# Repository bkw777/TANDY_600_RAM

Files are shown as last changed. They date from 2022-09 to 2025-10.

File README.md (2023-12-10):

# SRAM modules for TANDY 600

There are several versions to choose from. They all work the same. Just pick whichever you like based on size, cost of parts, ease of soldering, ease of installing, etc.

[Surface-Mount single-bank 96K](#standard-version) easy to solder, polarity keyed, more expensive  
[Through-Hole single-bank 96K](#through-hole-version) same as above, plus socketable/removable chips  
[Tiny single-bank 96K](#tiny-version) more difficult to solder, miniaturized mostly just as a stunt  
[Tiny dual-bank 192K](#dual-version) most practical way to get all 192K if you can manage the soldering

  
  
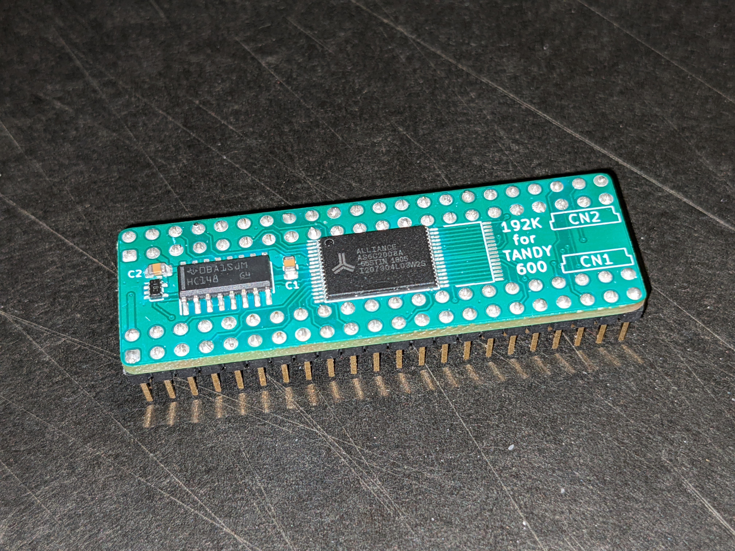
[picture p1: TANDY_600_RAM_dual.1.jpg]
  
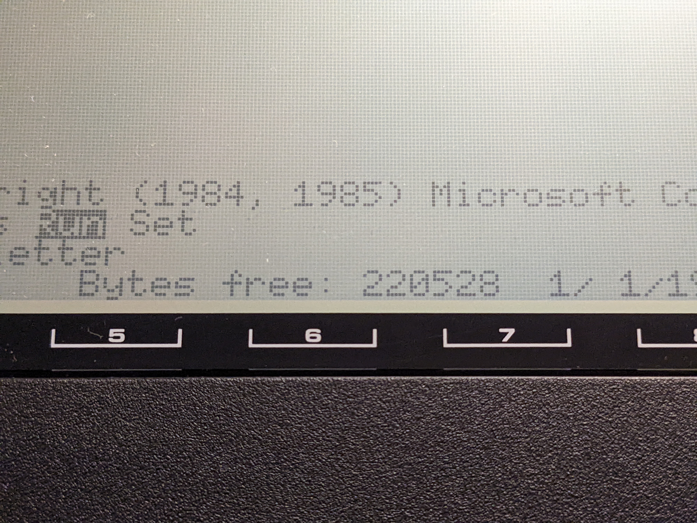
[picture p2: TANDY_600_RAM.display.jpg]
  

## Standard Version  
<!-- [PCB from OSHPark](https://oshpark.com/shared_projects/nBVWvJ2W)  -->
[PCB for STANDARD version from PCBWAY](https://www.pcbway.com/project/shareproject/TANDY_600_RAM.html)  
[BOM for STANDARD version from DigiKey](https://www.digikey.com/short/mjtb7rnn)

<!-- [Gerbers](../../releases/latest) -->

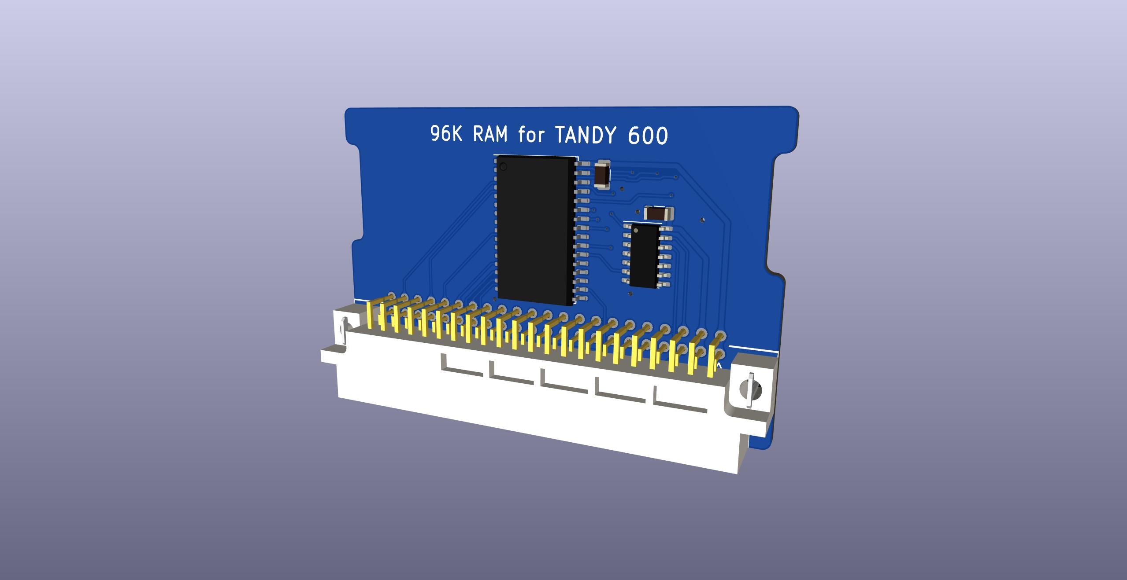
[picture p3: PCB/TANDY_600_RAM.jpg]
  
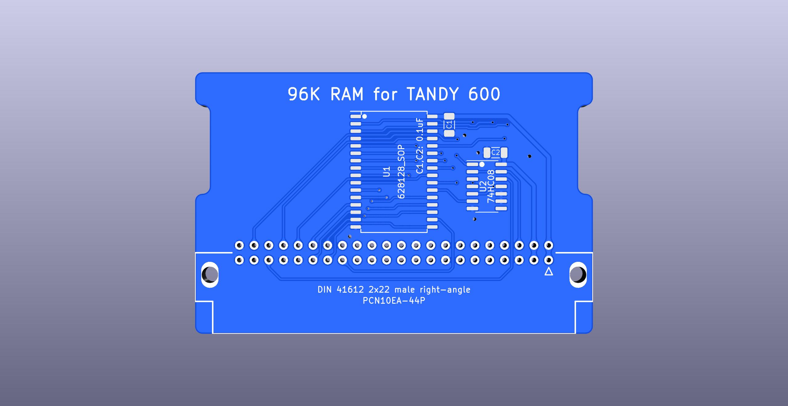
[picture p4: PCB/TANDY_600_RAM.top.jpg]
  
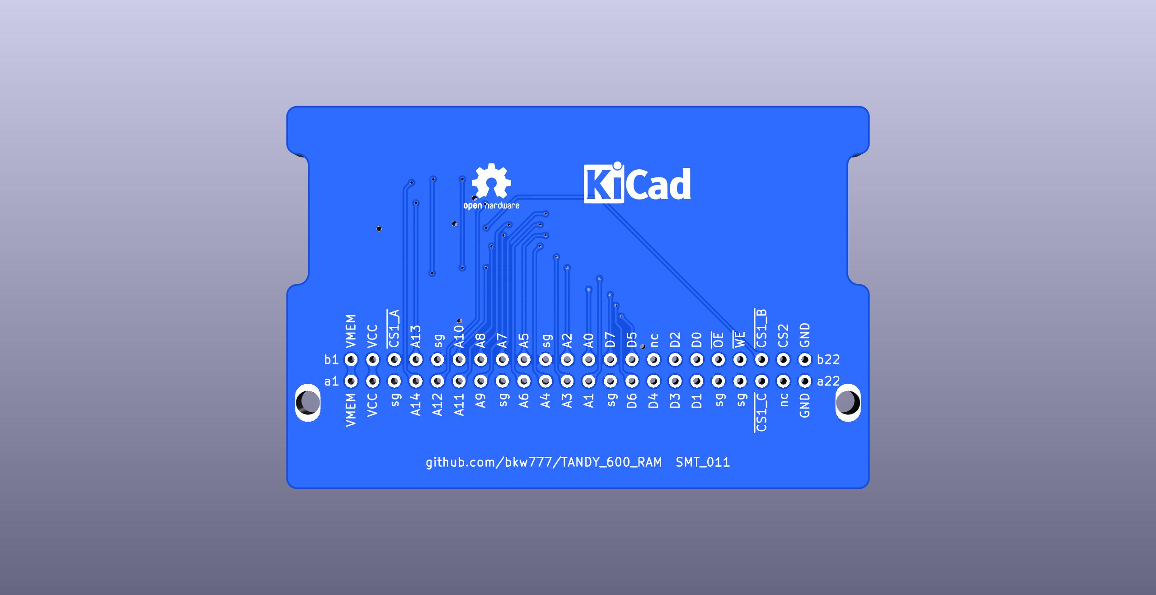
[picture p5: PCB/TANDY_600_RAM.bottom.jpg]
  
  
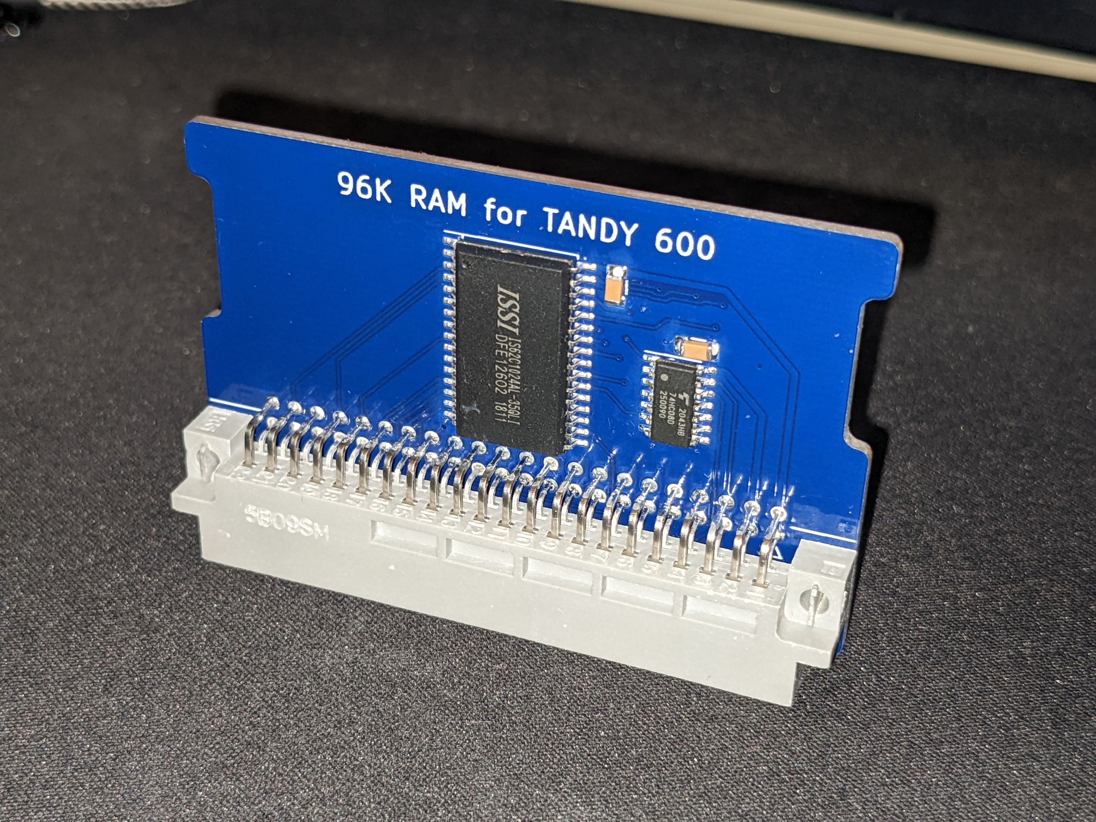
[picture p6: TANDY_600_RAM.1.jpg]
  
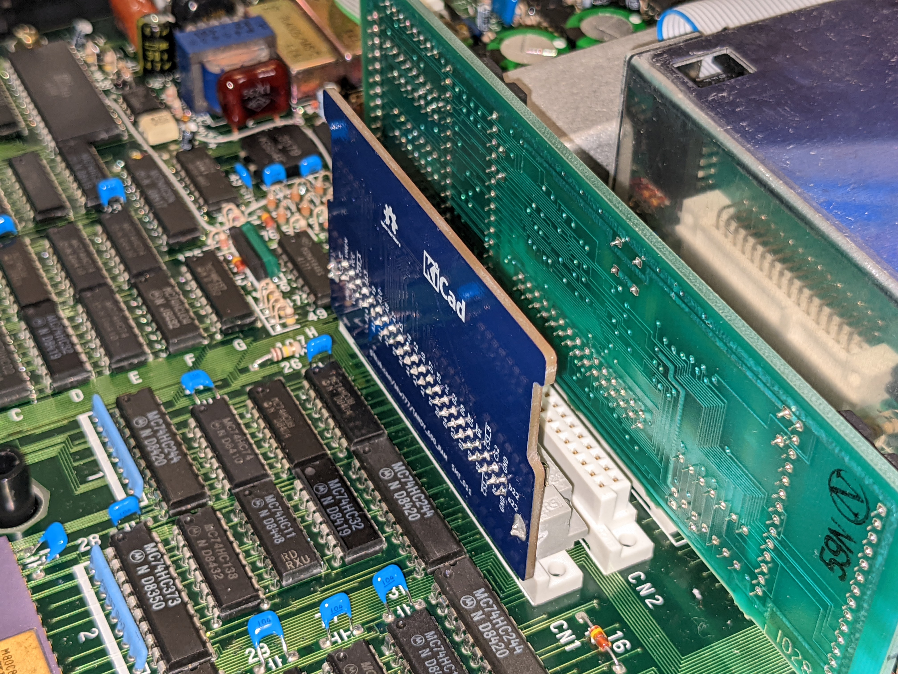
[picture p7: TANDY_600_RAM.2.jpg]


----

## Through-Hole Version  

Same schematic as the standard version, just with all through-hole components.  
The ICs may be socketed or not as you wish. When installed in the 600 there is room for both IC's on both boards to be socketed, and the BOM includes sockets.  

[PCB for THROUGH-HOLE version from PCBWAY](https://www.pcbway.com/project/shareproject/TANDY_600_RAM_96K_THT_70a7bb4c.html)  
[BOM for THROUGH-HOLE version from DigiKey](https://www.digikey.com/short/5q7bmv0q)

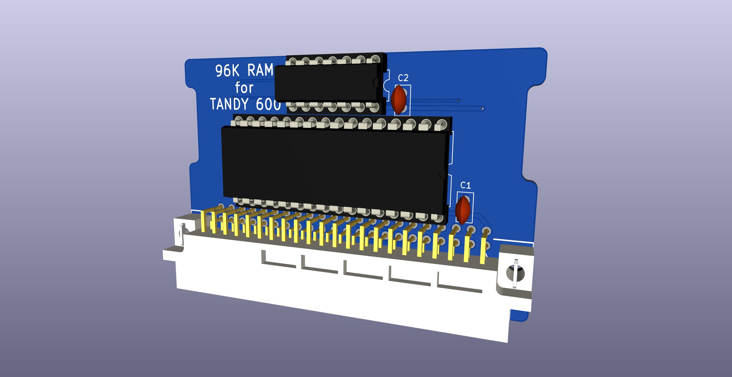
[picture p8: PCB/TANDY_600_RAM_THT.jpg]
  
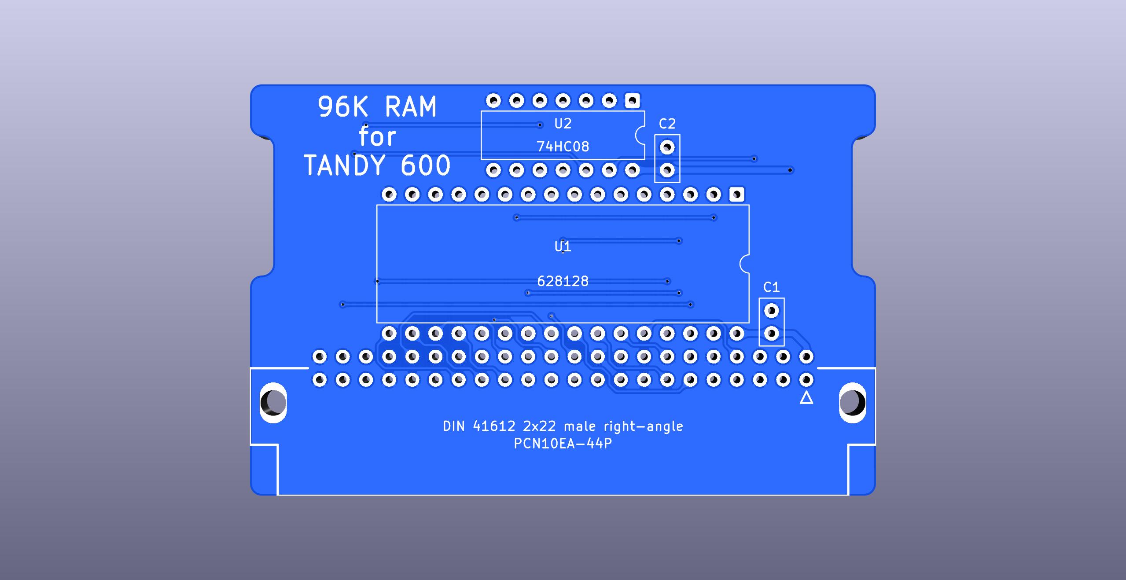
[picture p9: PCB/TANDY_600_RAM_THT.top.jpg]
  
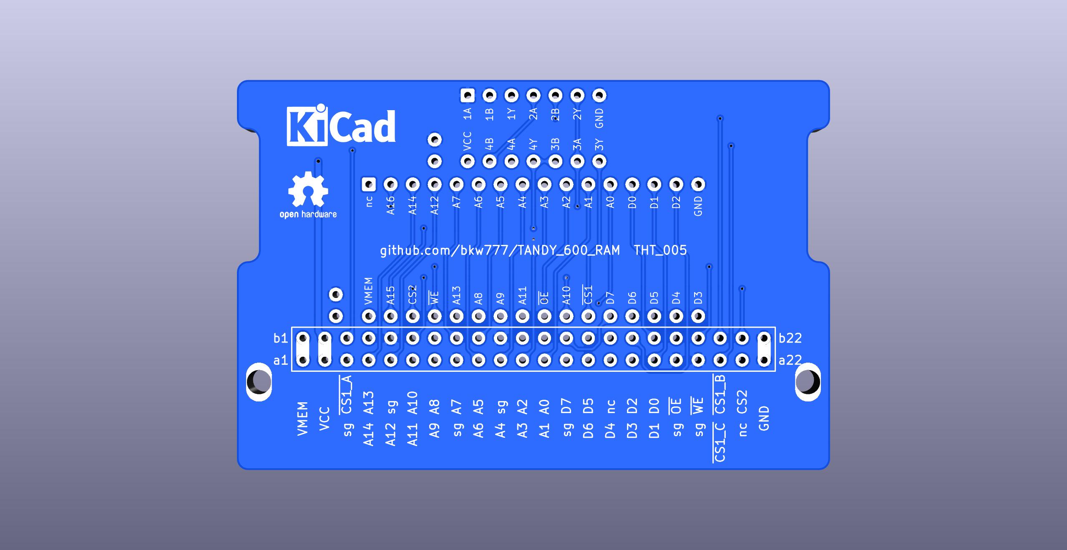
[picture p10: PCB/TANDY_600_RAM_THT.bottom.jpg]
  
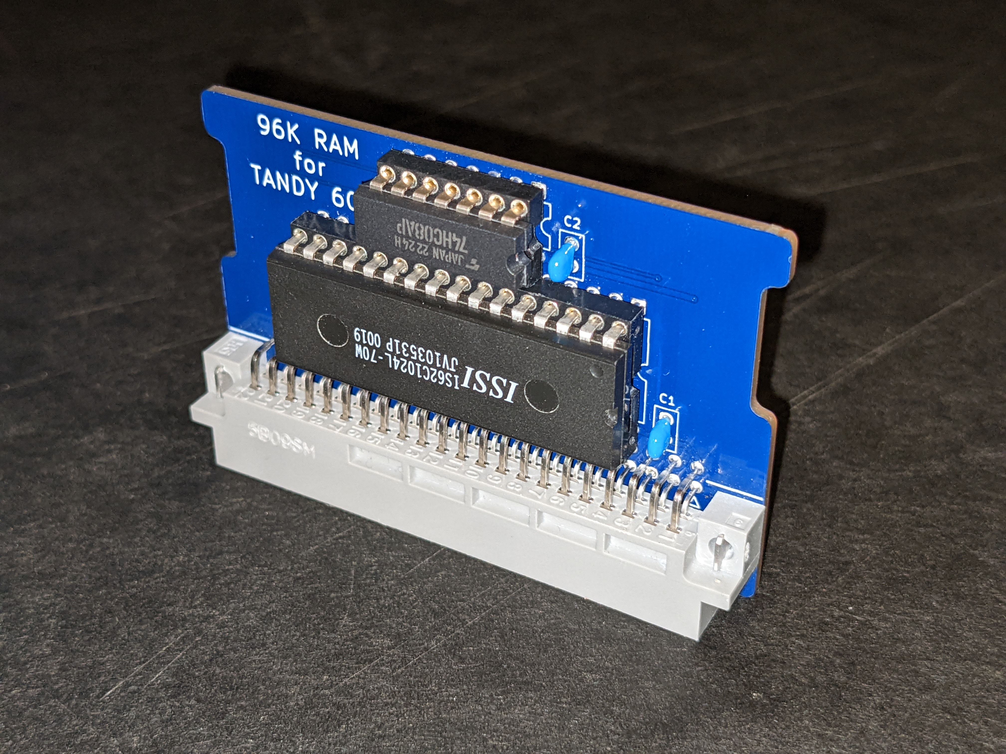
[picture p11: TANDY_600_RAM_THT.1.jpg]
  
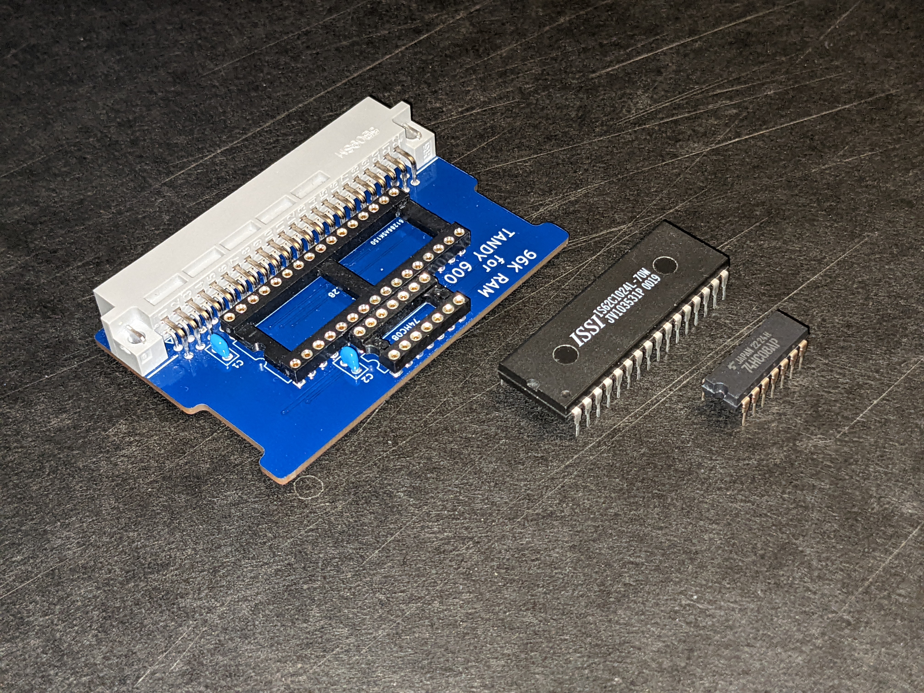
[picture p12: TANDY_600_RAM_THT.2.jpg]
  
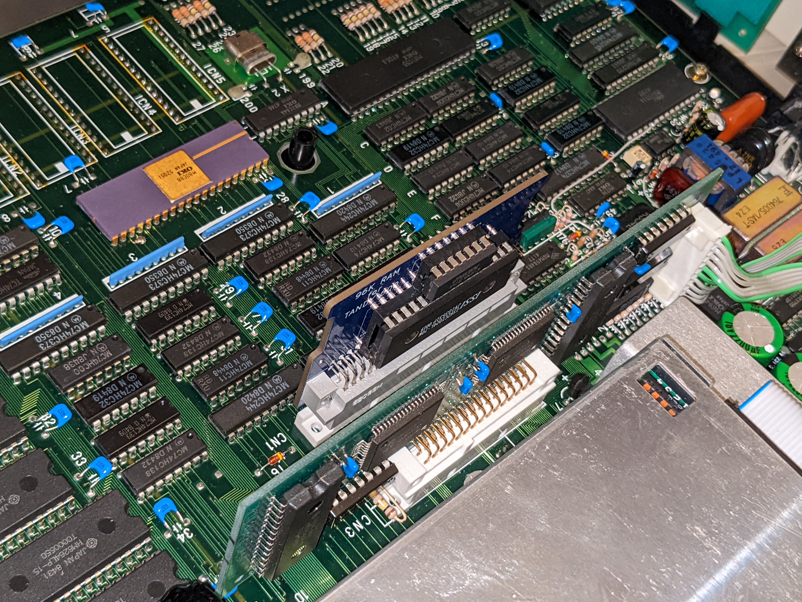
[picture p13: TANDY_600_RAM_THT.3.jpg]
  

----

## Tiny Version

[PCB for TINY version from PCBWAY](https://www.pcbway.com/project/shareproject/TANDY_600_RAM_TINY_Version_dedc5289.html)  
[BOM for TINY version from DigiKey](https://www.digikey.com/short/p907n2hq)

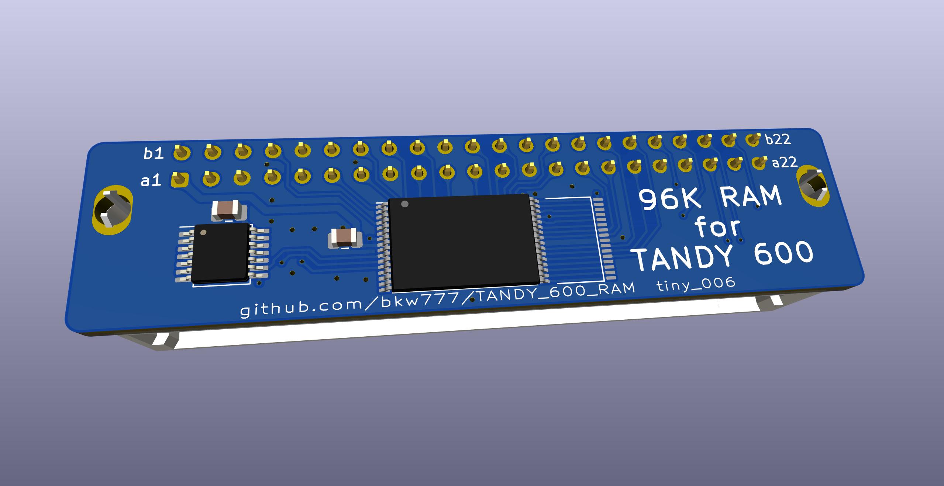
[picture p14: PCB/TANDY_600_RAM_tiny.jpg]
  
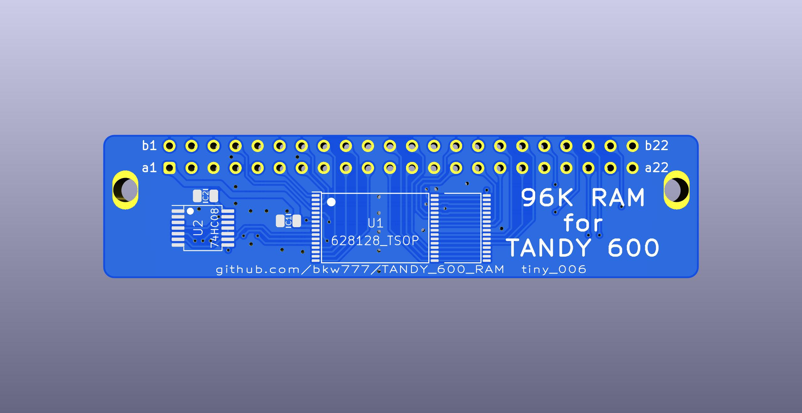
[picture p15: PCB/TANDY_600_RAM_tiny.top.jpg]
  
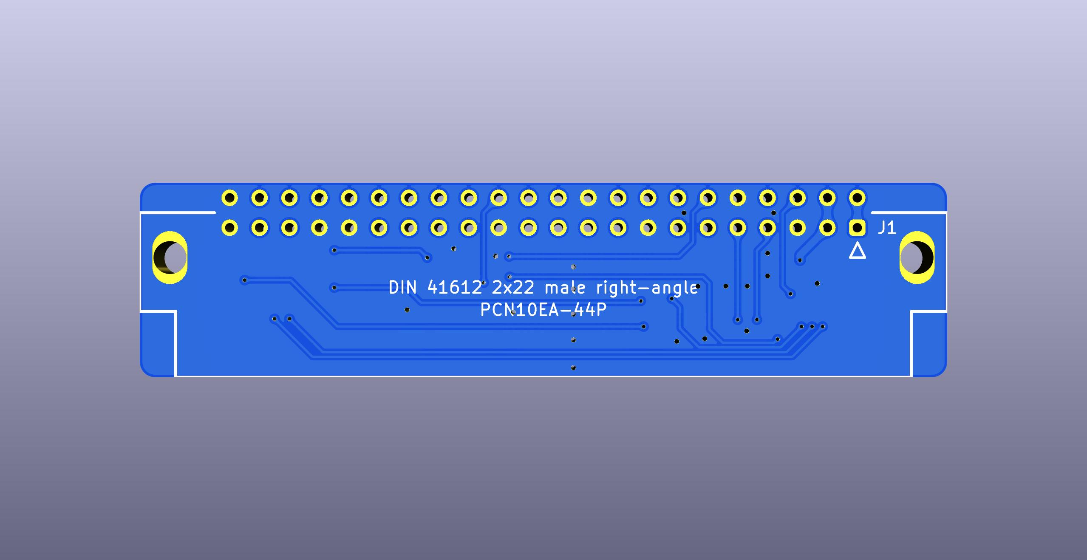
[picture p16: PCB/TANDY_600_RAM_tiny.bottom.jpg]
  
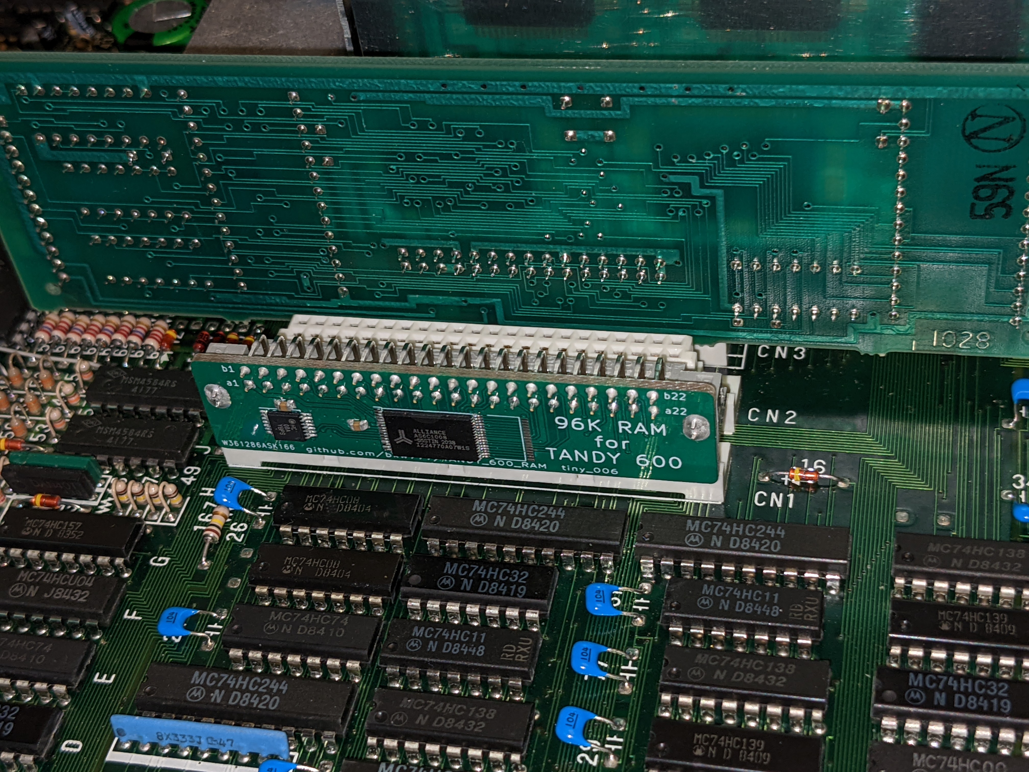
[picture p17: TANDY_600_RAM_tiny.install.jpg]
  

----

## DUAL VERSION

Single board that plugs into both CN1 and CN2 and supplies all 192K at once.  

<!-- [PCB from OSHPark]()  -->
[PCB for DUAL version from PCBWAY](https://www.pcbway.com/project/shareproject/TANDY_600_192K_DUAL_RAM_96d16a20.html)  
[BOM for DUAL version from DigiKey](https://www.digikey.com/short/h8bpf4wj)

  
  
  
  
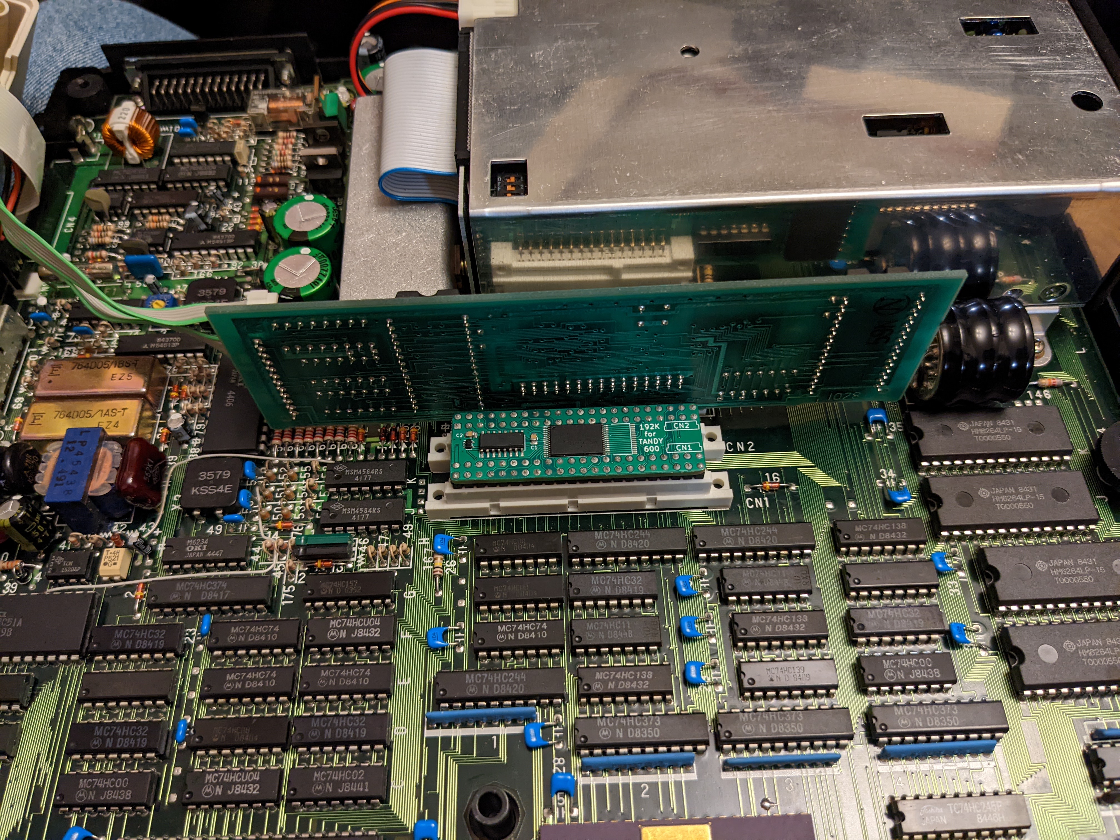
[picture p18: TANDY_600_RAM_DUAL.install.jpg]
  
  

----

# History / Credits

In 2017 I asked on the Tandy Color Computer Facebook group [if anyone could clone a 96K ram board for Model 600](https://www.facebook.com/groups/2359462640/permalink/10154864662292641/), and Jayeson Lee-Steere produced [Model600Sram_v1.1](https://github.com/bkw777/TANDY_600_RAM/tree/JLS-1.1) and placed it in the public domain.  

This version is different now but started from that.

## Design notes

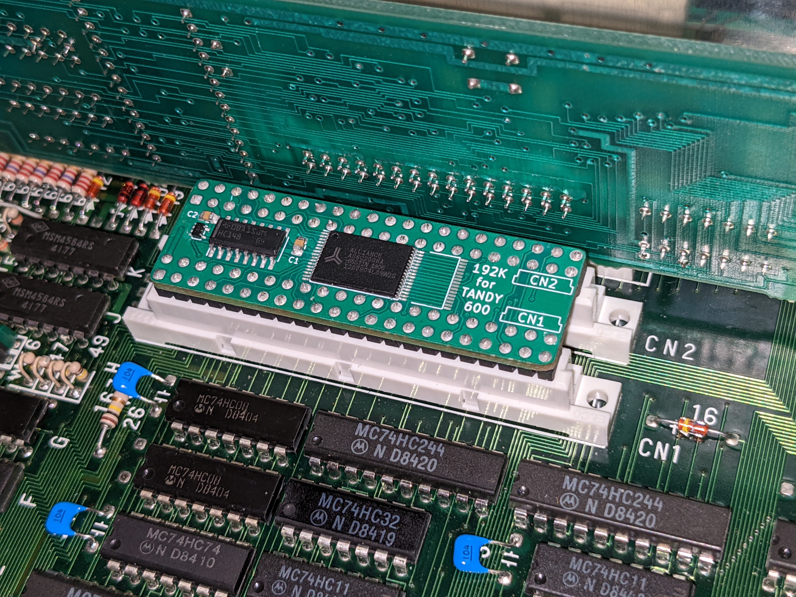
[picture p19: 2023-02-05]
TANDY_600_192K_AS62C2008A.jpg

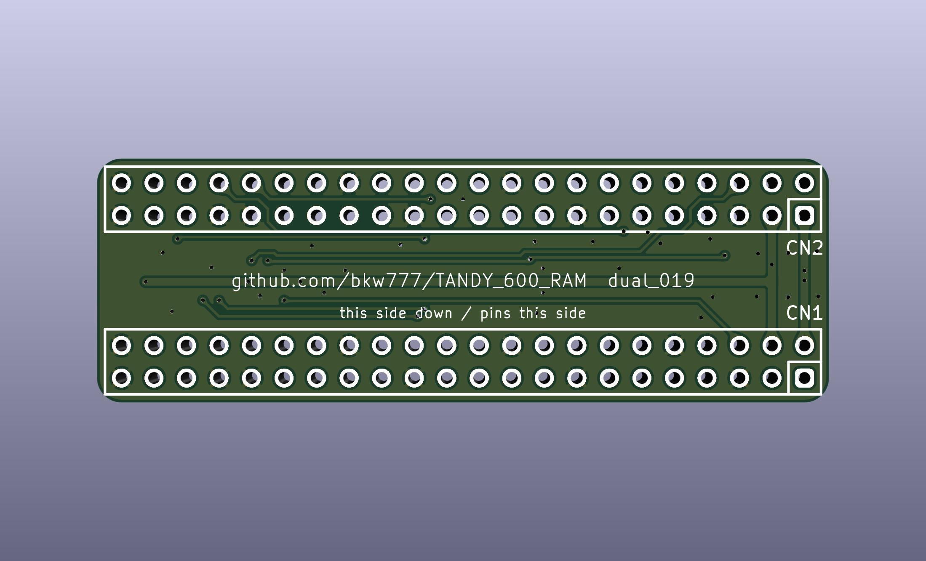
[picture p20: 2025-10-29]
PCB/out/TANDY_600_RAM_DUAL.bottom.jpg

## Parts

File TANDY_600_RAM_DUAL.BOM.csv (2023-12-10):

Index | Quantity | Part Number | Manufacturer Part Number | Description | Customer Reference | Available | Backorder | Unit Price | Extended Price USD
1 | 1 | 296-26468-1-ND | SN74HC148DR | IC PRIORITY ENCOD 1 X 8:3 16SOIC |  | 1 | 0 | 0.44000 | 0.44
2 | 1 | 1450-1029-ND | AS6C4008-55STIN | IC SRAM 4MBIT PARALLEL 32STSOP |  | 1 | 0 | 5.16000 | 5.16
3 | 1 | 1727-6062-1-ND | 74LVC1G02GW,125 | IC GATE NOR 1CH 2-INP 5TSSOP |  | 1 | 0 | 0.38000 | 0.38
4 | 2 | 478-12795-1-ND | KGM21NR71C104MT | CAP CER 0.1UF 16V X7R 0805 |  | 2 | 0 | 0.23000 | 0.46
5 | 2 | S2011EC-22-ND | PRPC022DAAN-RC | CONN HEADER VERT 44POS 2.54MM |  | 2 | 0 | 0.82000 | 1.64
6 | 1 | RMCF0805JT200KCT-ND | RMCF0805JT200K | RES 200K OHM 5% 1/8W 0805 |  | 1 | 0 | 0.10000 | 0.10

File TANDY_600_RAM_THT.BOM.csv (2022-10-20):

Index | Quantity | Part Number | Manufacturer Part Number | Description | Customer Reference | Available | Backorder | Unit Price | Extended Price USD
1 | 1 | 2057-ICM-632-1-GT-HT-ND | ICM-632-1-GT-HT | MACHINE PIN SOCKET, IC, DIP, 32P |  | 1 | 0 | 1.46000 | 1.46
2 | 1 | 1450-1017-ND | AS6C1008-55PCN | IC SRAM 1MBIT PARALLEL 32DIP |  | 1 | 0 | 4.01000 | 4.01
3 | 1 | H124256-ND | PCN10EA-44P-2.54DS(72) | CONN DIN HDR 44POS PCB RA GOLD |  | 1 | 0 | 6.17000 | 6.17
4 | 1 | ED3014-ND | SA143000 | CONN IC DIP SOCKET 14POS GOLD |  | 1 | 0 | 0.73000 | 0.73
5 | 1 | TC74HC08APF-ND | TC74HC08APF | IC GATE AND 4CH 2-INP 14DIP |  | 1 | 0 | 0.47000 | 0.47
6 | 2 | 56-K104K15X7RF5UL2CT-ND | K104K15X7RF5UL2 | CAP CER 0.1UF 50V X7R RADIAL |  | 2 | 0 | 0.23000 | 0.46

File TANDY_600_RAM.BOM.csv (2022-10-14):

Index | Quantity | Part Number | Manufacturer Part Number | Description | Customer Reference | Available | Backorder | Unit Price | Extended Price USD
1 | 1 | R1LP0108ESN-5SI#B1-ND | R1LP0108ESN-5SI#B1 | IC SRAM 1MBIT PARALLEL 32SOP |  | 1 | 0 | 3.28000 | 3.28
2 | 1 | H124256-ND | PCN10EA-44P-2.54DS(72) | CONN DIN HDR 44POS PCB RA GOLD |  | 1 | 0 | 6.17000 | 6.17
3 | 2 | 399-C1206C104K4RAC7800CT-ND | C1206C104K4RAC7800 | CAP CER 0.1UF 16V X7R 1206 |  | 2 | 0 | 0.11000 | 0.22
4 | 1 | 74HC08DCT-ND | 74HC08D | IC GATE AND 4CH 2-INP 14SOIC |  | 1 | 0 | 0.46000 | 0.46
5 | 1 | 1450-1018-ND | AS6C1008-55SIN | IC SRAM 1MBIT PARALLEL 32SOP |  | 1 | 0 | 3.21000 | 3.21

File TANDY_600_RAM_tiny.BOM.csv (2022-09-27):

Index | Quantity | Part Number | Manufacturer Part Number | Description | Customer Reference | Available | Backorder | Unit Price | Extended Price USD
1 | 1 | 1450-1019-ND | AS6C1008-55STIN | IC SRAM 1MBIT PARALLEL 32STSOP |  | 1 | 0 | 3.33000 | 3.33
2 | 2 | 732-8045-1-ND | 885012207045 | CAP CER 0.1UF 16V X7R 0805 |  | 2 | 0 | 0.10000 | 0.20
3 | 1 | H124256-ND | PCN10EA-44P-2.54DS(72) | CONN DIN HDR 44POS PCB RA GOLD |  | 1 | 0 | 6.17000 | 6.17
4 | 1 | MC74HC08ADTR2GOSCT-ND | MC74HC08ADTR2G | IC GATE AND 4CH 2-INP 14TSSOP |  | 1 | 0 | 0.64000 | 0.64

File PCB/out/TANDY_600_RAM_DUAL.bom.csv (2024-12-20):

Reference | Value | Datasheet | Footprint | Qty | DNP | MPN | Description
C1,C2 | 1u | datasheets/CL21B105KAFNNNE.pdf | 000_LOCAL:C_0805 | 2 |  | CL21B105KAFNNNE | CAP CER 1UF 25V X7R 0805
CN1,CN2 | TANDY_600_RAM_BUS_plain_pins | datasheets/PRPC022DAAN-RC.pdf | 000_LOCAL:DIN-41612_02x22_male_vertical_bare_pins | 2 |  | PRPC022DAAN-RC | CONN HEADER VERT 44POS 2.54MM
R1 | 200k | datasheets/sei-rmcf_rmcp.pdf | 000_LOCAL:R_0805 | 1 |  | RMCF0805FT200K | RES 200K OHM 1% 1/8W 0805
U1 | AS6C2008A | datasheets/AS6C4008.pdf | 000_LOCAL:TSOP32-dual | 1 |  | AS6C4008-55STIN | IC SRAM 4MBIT PARALLEL 32STSOP
U2 | HC148 | datasheets/HC148.pdf | 000_LOCAL:SOIC-16_3.9x9.9mm_P1.27mm | 1 |  | SN74HC148DR | IC PRIORITY ENCOD 1 X 8:3 16SOIC
U3 | 1G02 | datasheets/1G02.pdf | 000_LOCAL:SOT-353_SC-70-5 | 1 |  | SN74AHC1G02DCKR | IC GATE NOR 1CH 2-INP SC70-5

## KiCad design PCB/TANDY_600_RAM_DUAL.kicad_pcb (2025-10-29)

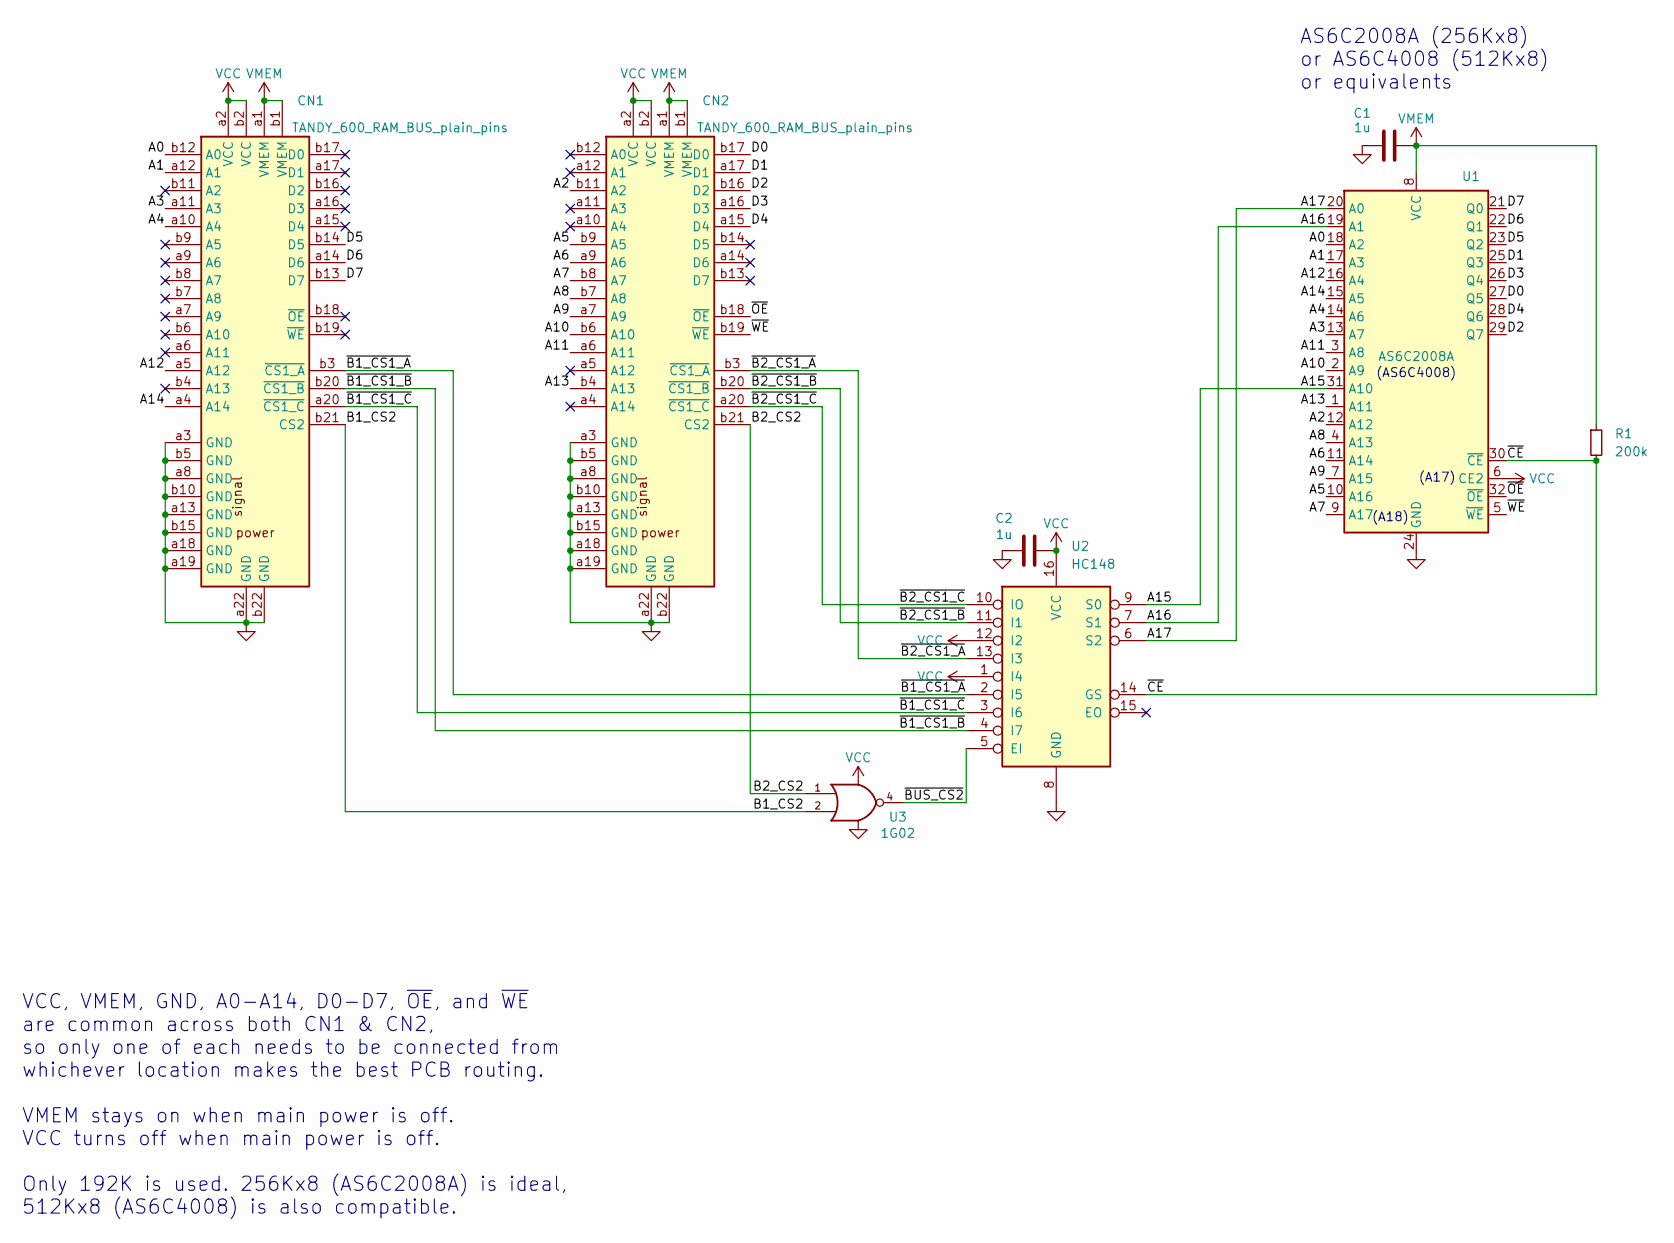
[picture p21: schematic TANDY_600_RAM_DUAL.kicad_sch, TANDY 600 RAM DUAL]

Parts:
C1, C2: 1u; C_0805; MPN CL21B105KAFNNNE
CN1, CN2: TANDY_600_RAM_BUS_plain_pins; DIN-41612_02x22_male_vertical_bare_pins; MPN PRPC022DAAN-RC
R1: 200k; R_0805; MPN RMCF0805FT200K
U1: AS6C2008A; TSOP32-dual; MPN AS6C4008-55STIN
U2: HC148; SOIC-16_3.9x9.9mm_P1.27mm; MPN SN74HC148DR
U3: 1G02; SOT-353_SC-70-5; MPN SN74AHC1G02DCKR

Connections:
/A0: CN1.b12 (A0), U1.18 (A2)
/A1: CN1.a12 (A1), U1.17 (A3)
/A2: CN2.b11 (A2), U1.12 (A12)
/A3: CN1.a11 (A3), U1.13 (A7)
/A4: CN1.a10 (A4), U1.14 (A6)
/A5: CN2.b9 (A5), U1.10 (A16)
/A6: CN2.a9 (A6), U1.11 (A14)
/A7: CN2.b8 (A7), U1.9 (A17)
/A8: CN2.b7 (A8), U1.4 (A13)
/A9: CN2.a7 (A9), U1.7 (A15)
/A10: CN2.b6 (A10), U1.2 (A9)
/A11: CN2.a6 (A11), U1.3 (A8)
/A12: CN1.a5 (A12), U1.16 (A4)
/A13: CN2.b4 (A13), U1.1 (A11)
/A14: CN1.a4 (A14), U1.15 (A5)
/A15: U1.31 (A10), U2.9 (S0)
/A16: U1.19 (A1), U2.7 (S1)
/A17: U1.20 (A0), U2.6 (S2)
/B1_CS2: CN1.b21 (CS2), U3.2
/B2_CS2: CN2.b21 (CS2), U3.1
/D0: CN2.b17 (D0), U1.27 (Q5)
/D1: CN2.a17 (D1), U1.25 (Q3)
/D2: CN2.b16 (D2), U1.29 (Q7)
/D3: CN2.a16 (D3), U1.26 (Q4)
/D4: CN2.a15 (D4), U1.28 (Q6)
/D5: CN1.b14 (D5), U1.23 (Q2)
/D6: CN1.a14 (D6), U1.22 (Q1)
/D7: CN1.b13 (D7), U1.21 (Q0)
/~B1_CS1_A: CN1.b3 (~CS1_A), U2.2 (I5)
/~B1_CS1_B: CN1.b20 (~CS1_B), U2.4 (I7)
/~B1_CS1_C: CN1.a20 (~CS1_C), U2.3 (I6)
/~B2_CS1_A: CN2.b3 (~CS1_A), U2.13 (I3)
/~B2_CS1_B: CN2.b20 (~CS1_B), U2.11 (I1)
/~B2_CS1_C: CN2.a20 (~CS1_C), U2.10 (IO)
/~BUS_CS2: U2.5 (EI), U3.4
/~CE: R1.2, U1.30 (~CE), U2.14 (GS)
/~OE: CN2.b18 (~OE), U1.32 (~OE)
/~WE: CN2.b19 (~WE), U1.5 (~WE)
GND: C1.2, C2.2, CN1.a3 (GND), CN1.a8 (GND), CN1.a13 (GND), CN1.a18 (GND), CN1.a19 (GND), CN1.a22 (GND), CN1.b5 (GND), CN1.b10 (GND), CN1.b15 (GND), CN1.b22 (GND), CN2.a3 (GND), CN2.a8 (GND), CN2.a13 (GND), CN2.a18 (GND), CN2.a19 (GND), CN2.a22 (GND), CN2.b5 (GND), CN2.b10 (GND), CN2.b15 (GND), CN2.b22 (GND), U1.24 (GND), U2.8 (GND), U3.3 (GND)
VCC: C2.1, CN1.a2 (VCC), CN1.b2 (VCC), CN2.a2 (VCC), CN2.b2 (VCC), U1.6 (CE2), U2.1 (I4), U2.12 (I2), U2.16 (VCC), U3.5 (VCC)
VMEM: C1.1, CN1.a1 (VMEM), CN1.b1 (VMEM), CN2.a1 (VMEM), CN2.b1 (VMEM), R1.1, U1.8 (VCC)

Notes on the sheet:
(A17)
VCC, VMEM, GND, A0-A14, D0-D7, ~{OE}, and ~{WE} are common across both CN1 & CN2, so only one of each needs to be connected from whichever location makes the best PCB routing. VMEM stays on when main power is off. VCC turns off when main power is off. Only 192K is used. 256Kx8 (AS6C2008A) is ideal,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
AS6C2008A (256Kx8) or AS6C4008 (512Kx8) or equivalents
(A18)
(AS6C4008)

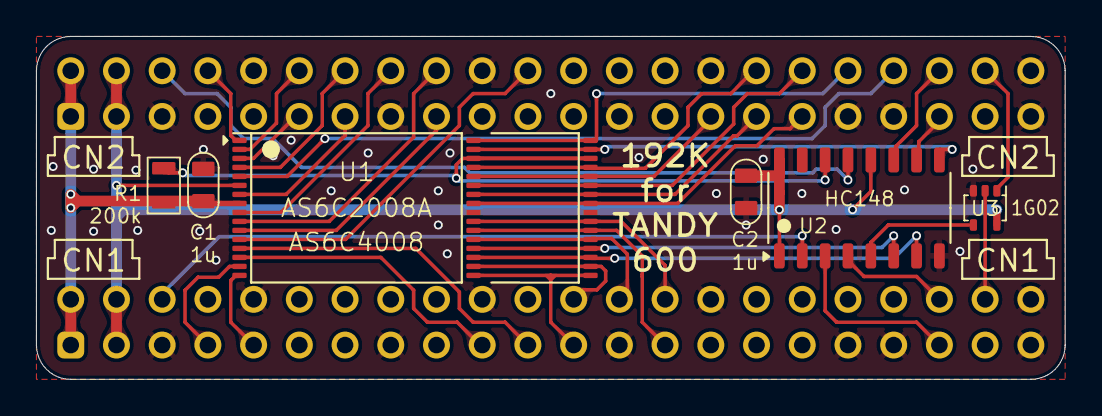
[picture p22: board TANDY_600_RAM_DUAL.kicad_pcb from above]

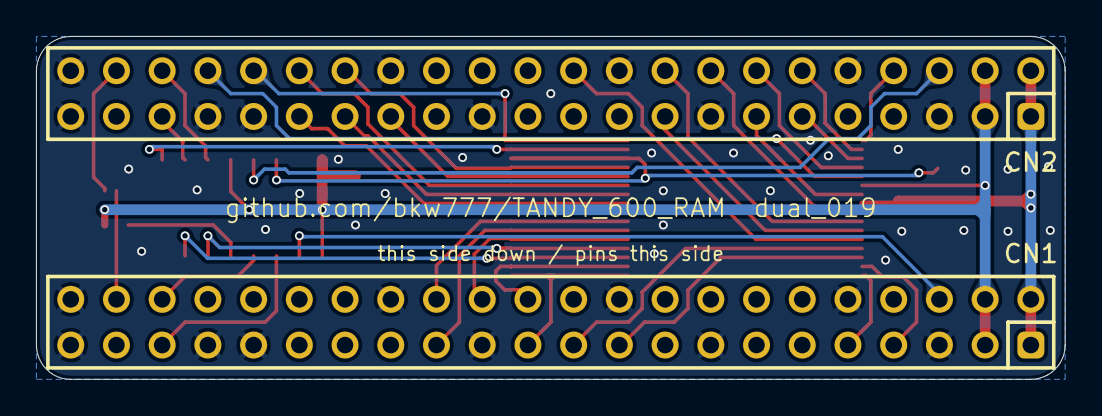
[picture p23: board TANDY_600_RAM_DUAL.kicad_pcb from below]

Board: 2 copper layers, 57.2 x 19.1 mm, 8 parts (2 on the bottom side), 41 nets.

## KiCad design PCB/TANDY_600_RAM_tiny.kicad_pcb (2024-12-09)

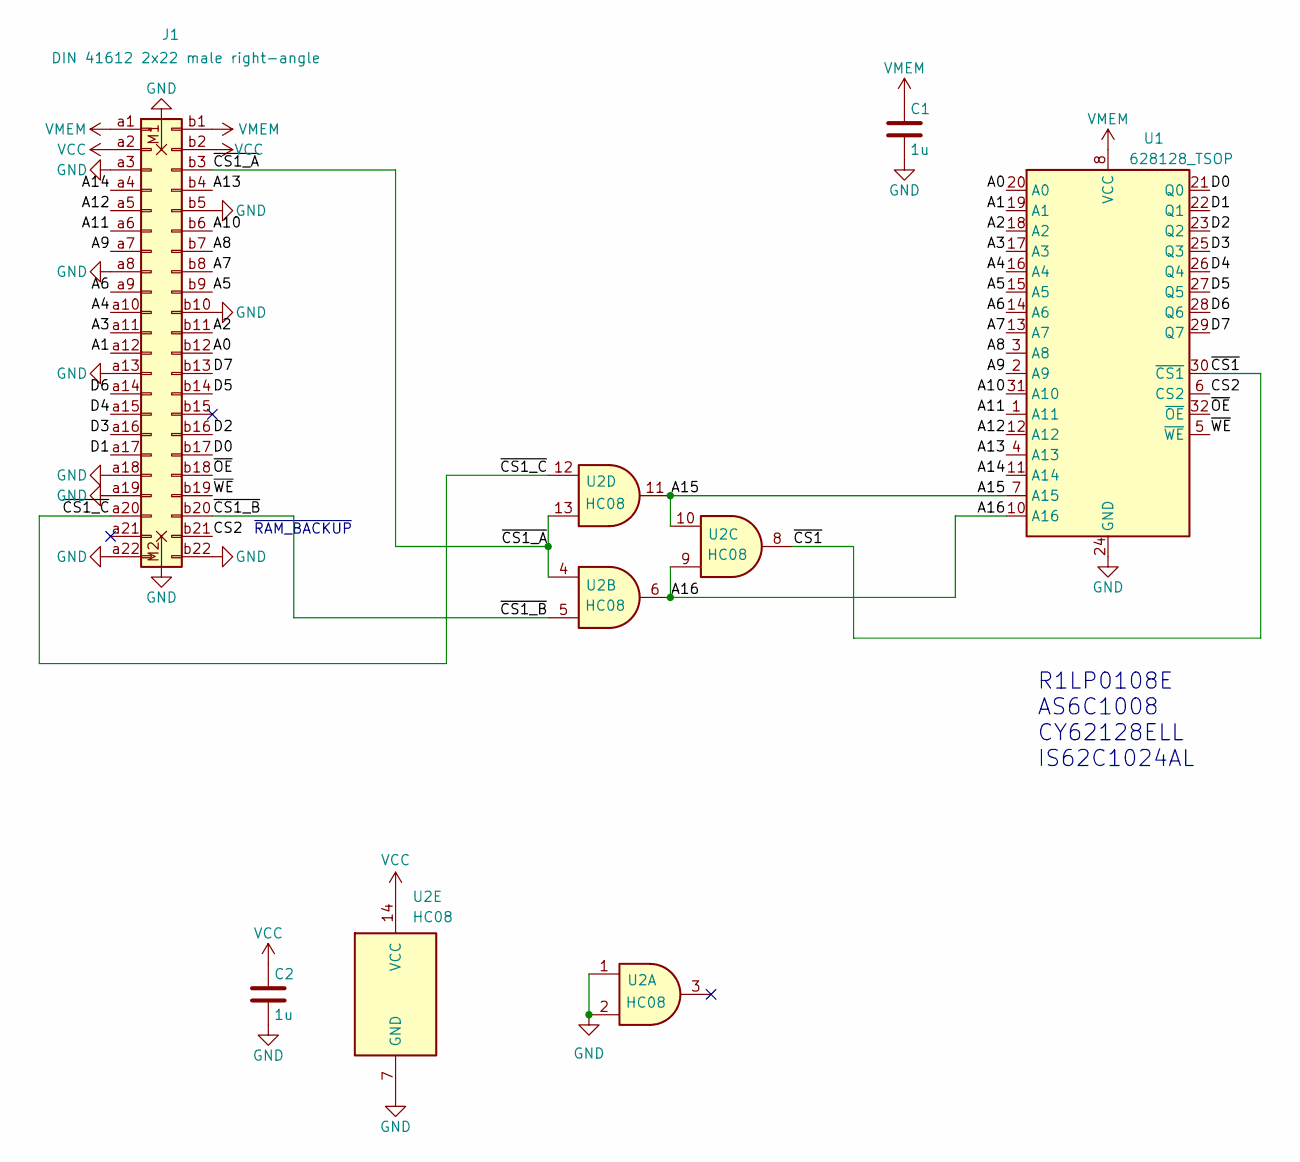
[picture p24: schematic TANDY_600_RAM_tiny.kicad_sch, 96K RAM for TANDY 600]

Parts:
C1, C2: 1u; C_0805
J1: DIN 41612 2x22 male right-angle; DIN-41612_02x22_male_horizontal
U1: 628128_TSOP; TSOP32-dual
U2: HC08; TSSOP-14_4.4x5mm_P0.65mm

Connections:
/A0: J1.b12, U1.20 (A0)
/A1: J1.a12, U1.19 (A1)
/A2: J1.b11, U1.18 (A2)
/A3: J1.a11, U1.17 (A3)
/A4: J1.a10, U1.16 (A4)
/A5: J1.b9, U1.15 (A5)
/A6: J1.a9, U1.14 (A6)
/A7: J1.b8, U1.13 (A7)
/A8: J1.b7, U1.3 (A8)
/A9: J1.a7, U1.2 (A9)
/A10: J1.b6, U1.31 (A10)
/A11: J1.a6, U1.1 (A11)
/A12: J1.a5, U1.12 (A12)
/A13: J1.b4, U1.4 (A13)
/A14: J1.a4, U1.11 (A14)
/A15: U1.7 (A15), U2.10, U2.11
/A16: U1.10 (A16), U2.6, U2.9
/CS2: J1.b21, U1.6 (CS2)
/D0: J1.b17, U1.21 (Q0)
/D1: J1.a17, U1.22 (Q1)
/D2: J1.b16, U1.23 (Q2)
/D3: J1.a16, U1.25 (Q3)
/D4: J1.a15, U1.26 (Q4)
/D5: J1.b14, U1.27 (Q5)
/D6: J1.a14, U1.28 (Q6)
/D7: J1.b13, U1.29 (Q7)
/~CS1_A: J1.b3, U2.4, U2.13
/~CS1_B: J1.b20, U2.5
/~CS1_C: J1.a20, U2.12
/~CS1: U1.30 (~CS1), U2.8
/~OE: J1.b18, U1.32 (~OE)
/~WE: J1.b19, U1.5 (~WE)
GND: C1.2, C2.2, J1.M1 (mount), J1.M2 (mount), J1.a3, J1.a8, J1.a13, J1.a18, J1.a19, J1.a22, J1.b5, J1.b10, J1.b22, U1.24 (GND), U2.1, U2.2, U2.7 (GND)
VCC: C2.1, J1.a2, J1.b2, U2.14 (VCC)
VMEM: C1.1, J1.a1, J1.b1, U1.8 (VCC)

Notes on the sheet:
~{RAM_BACKUP}
R1LP0108E AS6C1008 CY62128ELL IS62C1024AL

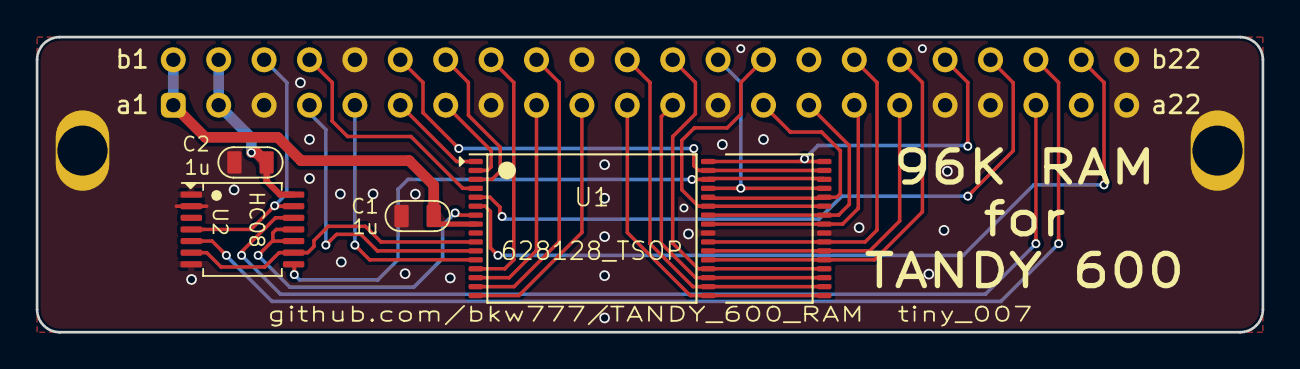
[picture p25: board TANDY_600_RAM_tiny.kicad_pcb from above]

Board: 2 copper layers, 68.6 x 16.5 mm, 5 parts (1 on the bottom side), 35 nets.

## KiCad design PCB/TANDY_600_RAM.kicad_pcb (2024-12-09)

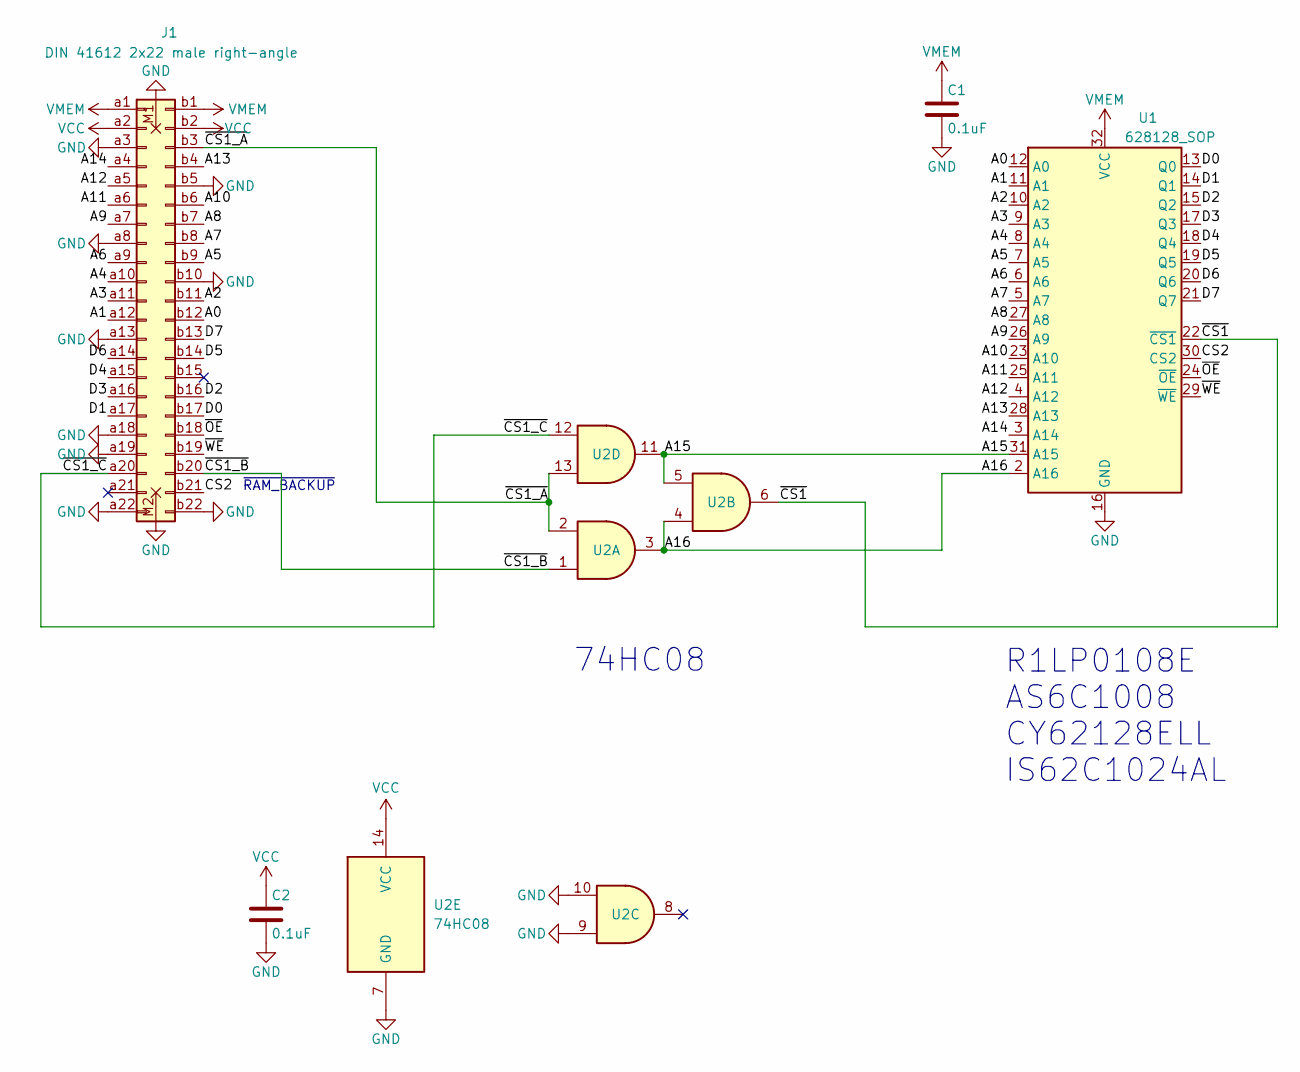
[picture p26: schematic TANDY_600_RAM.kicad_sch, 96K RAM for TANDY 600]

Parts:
C1, C2: 0.1uF; C_1206
J1: DIN 41612 2x22 male right-angle; DIN-41612_02x22_male_horizontal
U1: 628128_SOP; SOP-32W
U2: 74HC08; SOIC-14_3.9x8.7mm_P1.27mm

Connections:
/A0: J1.b12, U1.12 (A0)
/A1: J1.a12, U1.11 (A1)
/A2: J1.b11, U1.10 (A2)
/A3: J1.a11, U1.9 (A3)
/A4: J1.a10, U1.8 (A4)
/A5: J1.b9, U1.7 (A5)
/A6: J1.a9, U1.6 (A6)
/A7: J1.b8, U1.5 (A7)
/A8: J1.b7, U1.27 (A8)
/A9: J1.a7, U1.26 (A9)
/A10: J1.b6, U1.23 (A10)
/A11: J1.a6, U1.25 (A11)
/A12: J1.a5, U1.4 (A12)
/A13: J1.b4, U1.28 (A13)
/A14: J1.a4, U1.3 (A14)
/A15: U1.31 (A15), U2.5, U2.11
/A16: U1.2 (A16), U2.3, U2.4
/CS2: J1.b21, U1.30 (CS2)
/D0: J1.b17, U1.13 (Q0)
/D1: J1.a17, U1.14 (Q1)
/D2: J1.b16, U1.15 (Q2)
/D3: J1.a16, U1.17 (Q3)
/D4: J1.a15, U1.18 (Q4)
/D5: J1.b14, U1.19 (Q5)
/D6: J1.a14, U1.20 (Q6)
/D7: J1.b13, U1.21 (Q7)
/~CS1_A: J1.b3, U2.2, U2.13
/~CS1_B: J1.b20, U2.1
/~CS1_C: J1.a20, U2.12
/~CS1: U1.22 (~CS1), U2.6
/~OE: J1.b18, U1.24 (~OE)
/~WE: J1.b19, U1.29 (~WE)
GND: C1.2, C2.2, J1.M1 (mount), J1.M2 (mount), J1.a3, J1.a8, J1.a13, J1.a18, J1.a19, J1.a22, J1.b5, J1.b10, J1.b22, U1.16 (GND), U2.7 (GND), U2.9, U2.10
VCC: C2.1, J1.a2, J1.b2, U2.14 (VCC)
VMEM: C1.1, J1.a1, J1.b1, U1.32 (VCC)

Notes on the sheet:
~{RAM_BACKUP}
R1LP0108E AS6C1008 CY62128ELL IS62C1024AL
74HC08

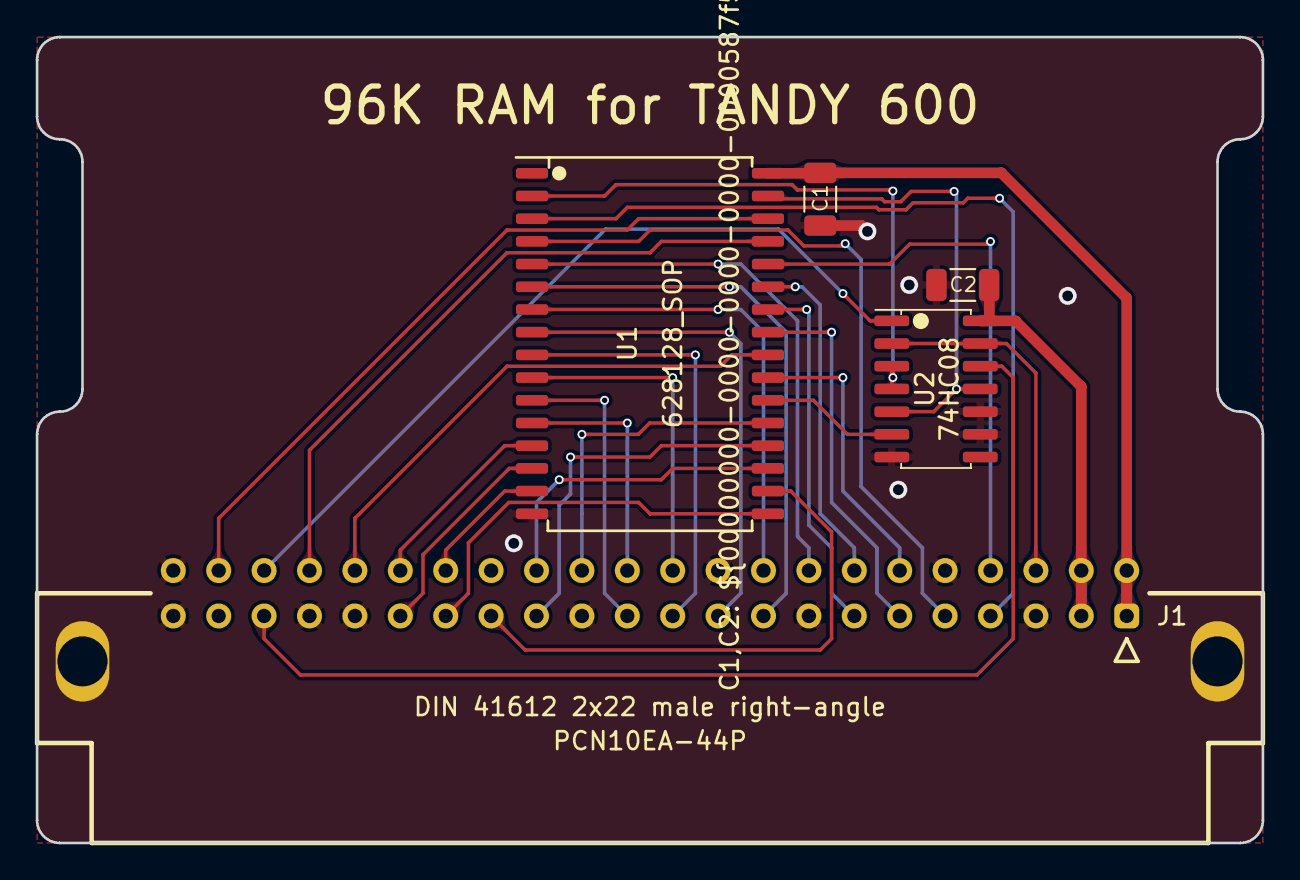
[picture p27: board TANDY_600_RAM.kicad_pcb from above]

Board: 2 copper layers, 68.6 x 45.1 mm, 5 parts (0 on the bottom side), 35 nets.

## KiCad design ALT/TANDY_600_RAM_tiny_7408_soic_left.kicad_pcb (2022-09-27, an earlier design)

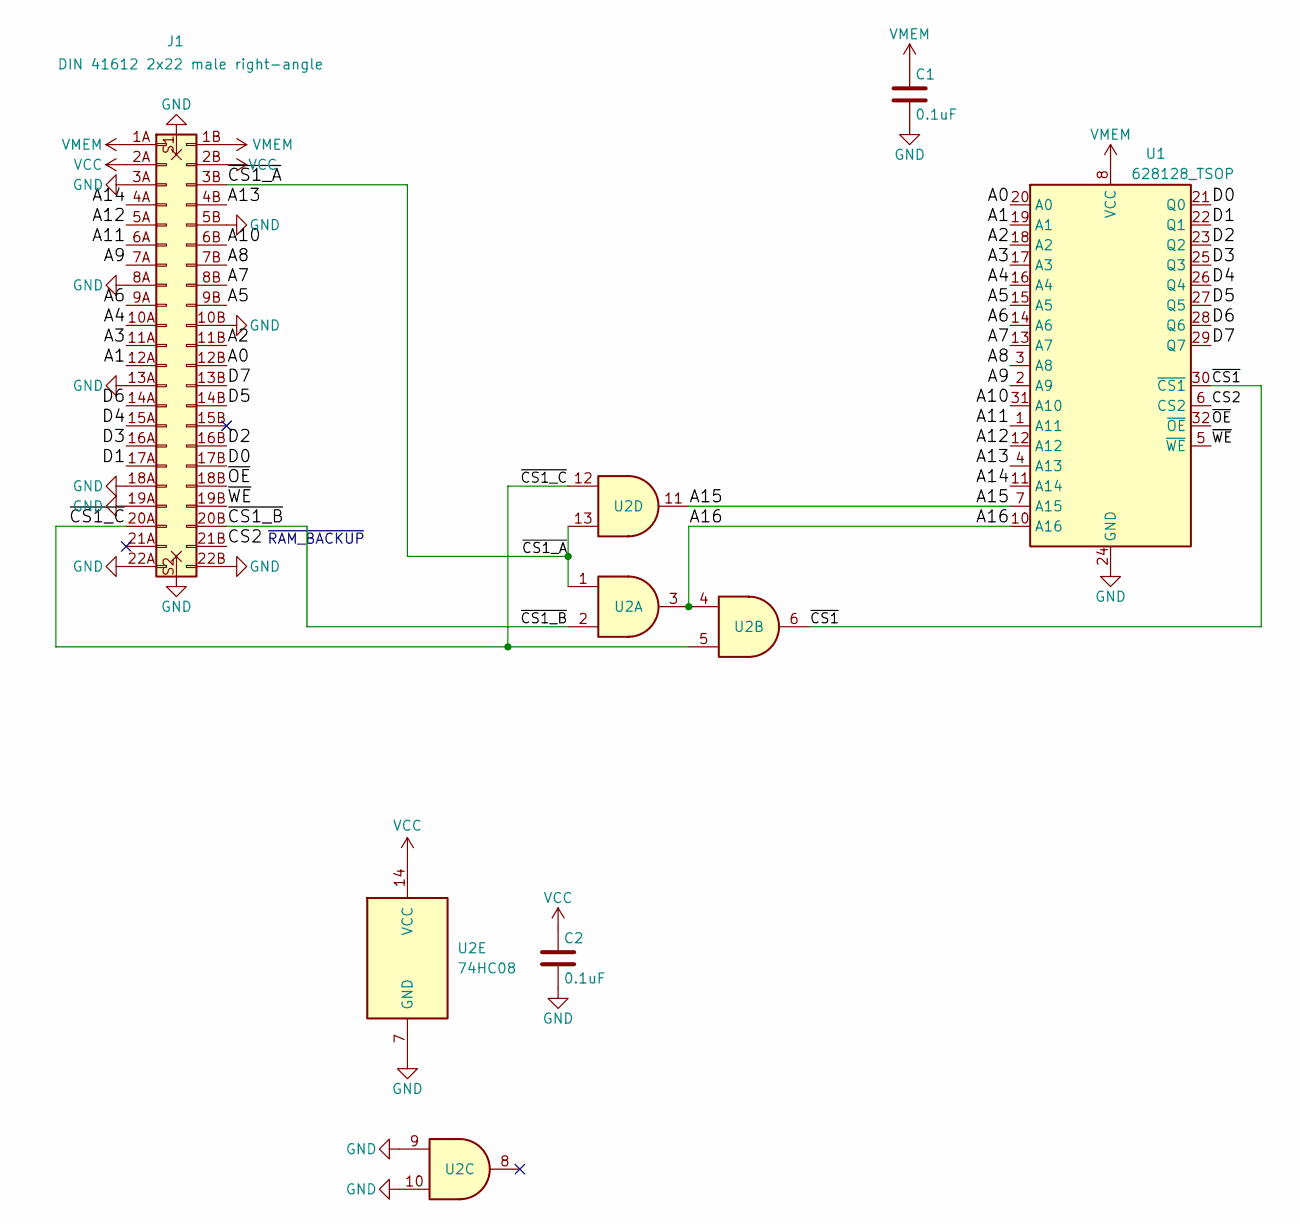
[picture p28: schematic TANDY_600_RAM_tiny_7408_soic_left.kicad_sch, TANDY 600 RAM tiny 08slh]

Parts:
C1, C2: 0.1uF; C_0805
J1: DIN 41612 2x22 male right-angle
U1: 628128_TSOP; TSOP32-dual
U2: 74HC08; SOIC-14_3.9x8.7mm_P1.27mm

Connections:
/A0: J1.12B, U1.20 (A0)
/A1: J1.12A, U1.19 (A1)
/A2: J1.11B, U1.18 (A2)
/A3: J1.11A, U1.17 (A3)
/A4: J1.10A, U1.16 (A4)
/A5: J1.9B, U1.15 (A5)
/A6: J1.9A, U1.14 (A6)
/A7: J1.8B, U1.13 (A7)
/A8: J1.7B, U1.3 (A8)
/A9: J1.7A, U1.2 (A9)
/A10: J1.6B, U1.31 (A10)
/A11: J1.6A, U1.1 (A11)
/A12: J1.5A, U1.12 (A12)
/A13: J1.4B, U1.4 (A13)
/A14: J1.4A, U1.11 (A14)
/A15: U1.7 (A15), U2.11
/A16: U1.10 (A16), U2.3, U2.4
/CS2: J1.21B, U1.6 (CS2)
/D0: J1.17B, U1.21 (Q0)
/D1: J1.17A, U1.22 (Q1)
/D2: J1.16B, U1.23 (Q2)
/D3: J1.16A, U1.25 (Q3)
/D4: J1.15A, U1.26 (Q4)
/D5: J1.14B, U1.27 (Q5)
/D6: J1.14A, U1.28 (Q6)
/D7: J1.13B, U1.29 (Q7)
/~CS1_A: J1.3B, U2.1, U2.13
/~CS1_B: J1.20B, U2.2
/~CS1_C: J1.20A, U2.5, U2.12
/~CS1: U1.30 (~CS1), U2.6
/~OE: J1.18B, U1.32 (~OE)
/~WE: J1.19B, U1.5 (~WE)
GND: C1.2, C2.2, J1.3A, J1.5B, J1.8A, J1.10B, J1.13A, J1.18A, J1.19A, J1.22A, J1.22B, J1.S1 (mount), J1.S2 (mount), U1.24 (GND), U2.7 (GND), U2.9, U2.10
VCC: C2.1, J1.2A, J1.2B, U2.14 (VCC)
VMEM: C1.1, J1.1A, J1.1B, U1.8 (VCC)

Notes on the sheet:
~{RAM_BACKUP}

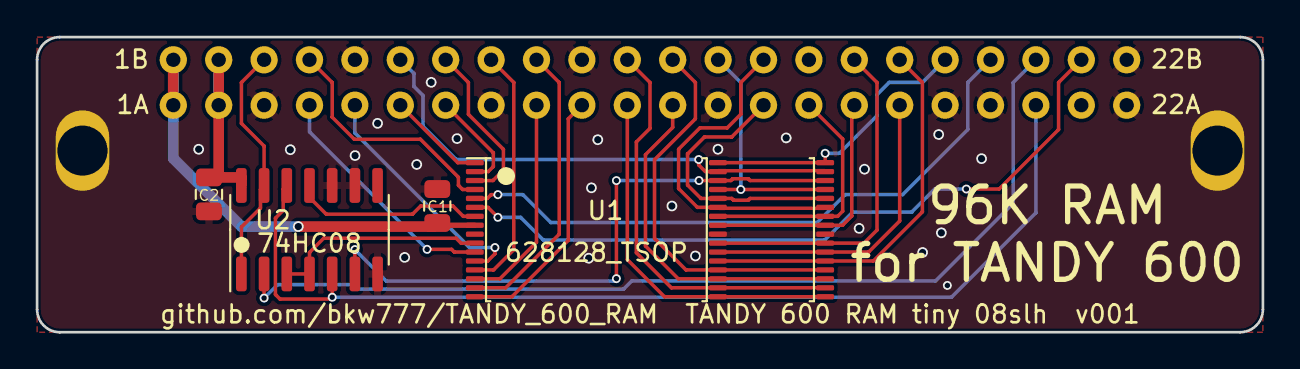
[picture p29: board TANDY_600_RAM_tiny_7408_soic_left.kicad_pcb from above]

Board: 2 copper layers, 68.6 x 16.5 mm, 5 parts (1 on the bottom side), 35 nets.

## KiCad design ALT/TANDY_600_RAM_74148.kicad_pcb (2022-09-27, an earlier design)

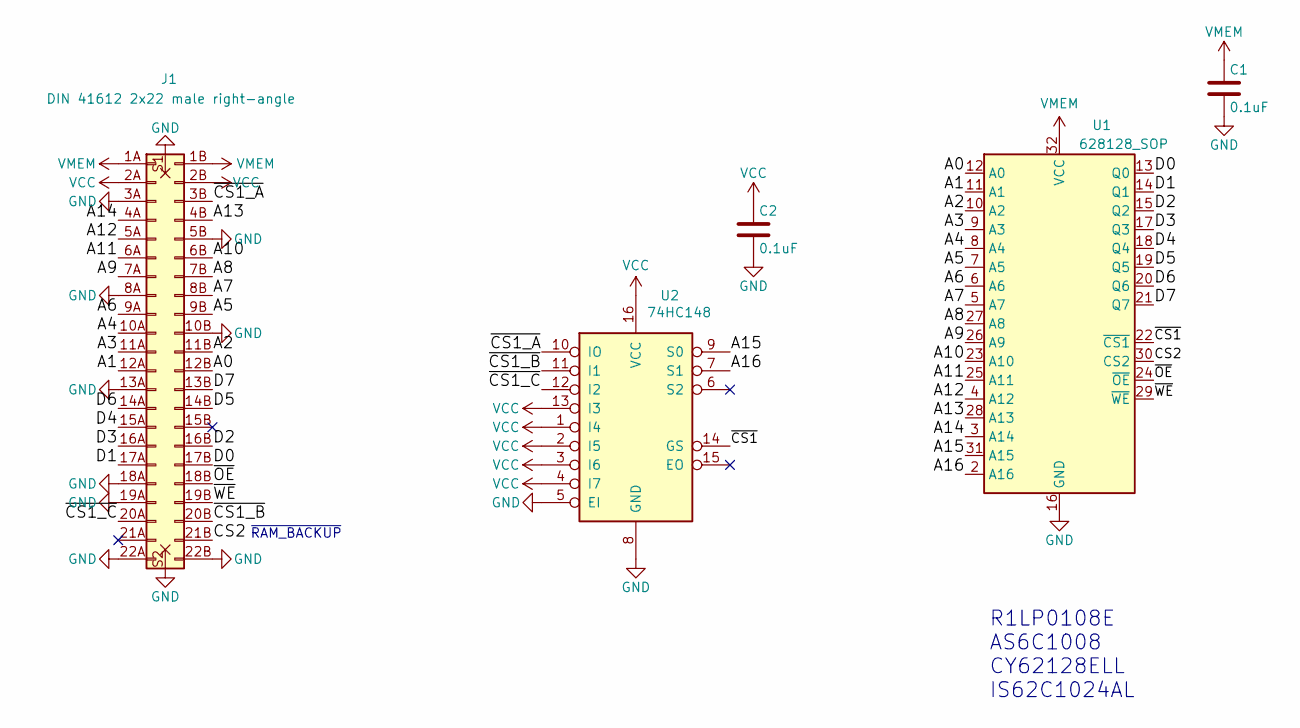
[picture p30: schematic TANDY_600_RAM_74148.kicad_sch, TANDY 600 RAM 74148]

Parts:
C1, C2: 0.1uF; C_1206
J1: DIN 41612 2x22 male right-angle
U1: 628128_SOP; SOP-32W
U2: 74HC148; SOIC-SOP-16

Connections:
/A0: J1.12B, U1.12 (A0)
/A1: J1.12A, U1.11 (A1)
/A2: J1.11B, U1.10 (A2)
/A3: J1.11A, U1.9 (A3)
/A4: J1.10A, U1.8 (A4)
/A5: J1.9B, U1.7 (A5)
/A6: J1.9A, U1.6 (A6)
/A7: J1.8B, U1.5 (A7)
/A8: J1.7B, U1.27 (A8)
/A9: J1.7A, U1.26 (A9)
/A10: J1.6B, U1.23 (A10)
/A11: J1.6A, U1.25 (A11)
/A12: J1.5A, U1.4 (A12)
/A13: J1.4B, U1.28 (A13)
/A14: J1.4A, U1.3 (A14)
/A15: U1.31 (A15), U2.9 (S0)
/A16: U1.2 (A16), U2.7 (S1)
/CS2: J1.21B, U1.30 (CS2)
/D0: J1.17B, U1.13 (Q0)
/D1: J1.17A, U1.14 (Q1)
/D2: J1.16B, U1.15 (Q2)
/D3: J1.16A, U1.17 (Q3)
/D4: J1.15A, U1.18 (Q4)
/D5: J1.14B, U1.19 (Q5)
/D6: J1.14A, U1.20 (Q6)
/D7: J1.13B, U1.21 (Q7)
/~CS1_A: J1.3B, U2.10 (IO)
/~CS1_B: J1.20B, U2.11 (I1)
/~CS1_C: J1.20A, U2.12 (I2)
/~CS1: U1.22 (~CS1), U2.14 (GS)
/~OE: J1.18B, U1.24 (~OE)
/~WE: J1.19B, U1.29 (~WE)
GND: C1.2, C2.2, J1.3A, J1.5B, J1.8A, J1.10B, J1.13A, J1.18A, J1.19A, J1.22A, J1.22B, J1.S1 (mount), J1.S2 (mount), U1.16 (GND), U2.5 (EI), U2.8 (GND)
VCC: C2.1, J1.2A, J1.2B, U2.1 (I4), U2.2 (I5), U2.3 (I6), U2.4 (I7), U2.13 (I3), U2.16 (VCC)
VMEM: C1.1, J1.1A, J1.1B, U1.32 (VCC)

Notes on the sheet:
~{RAM_BACKUP}
R1LP0108E AS6C1008 CY62128ELL IS62C1024AL

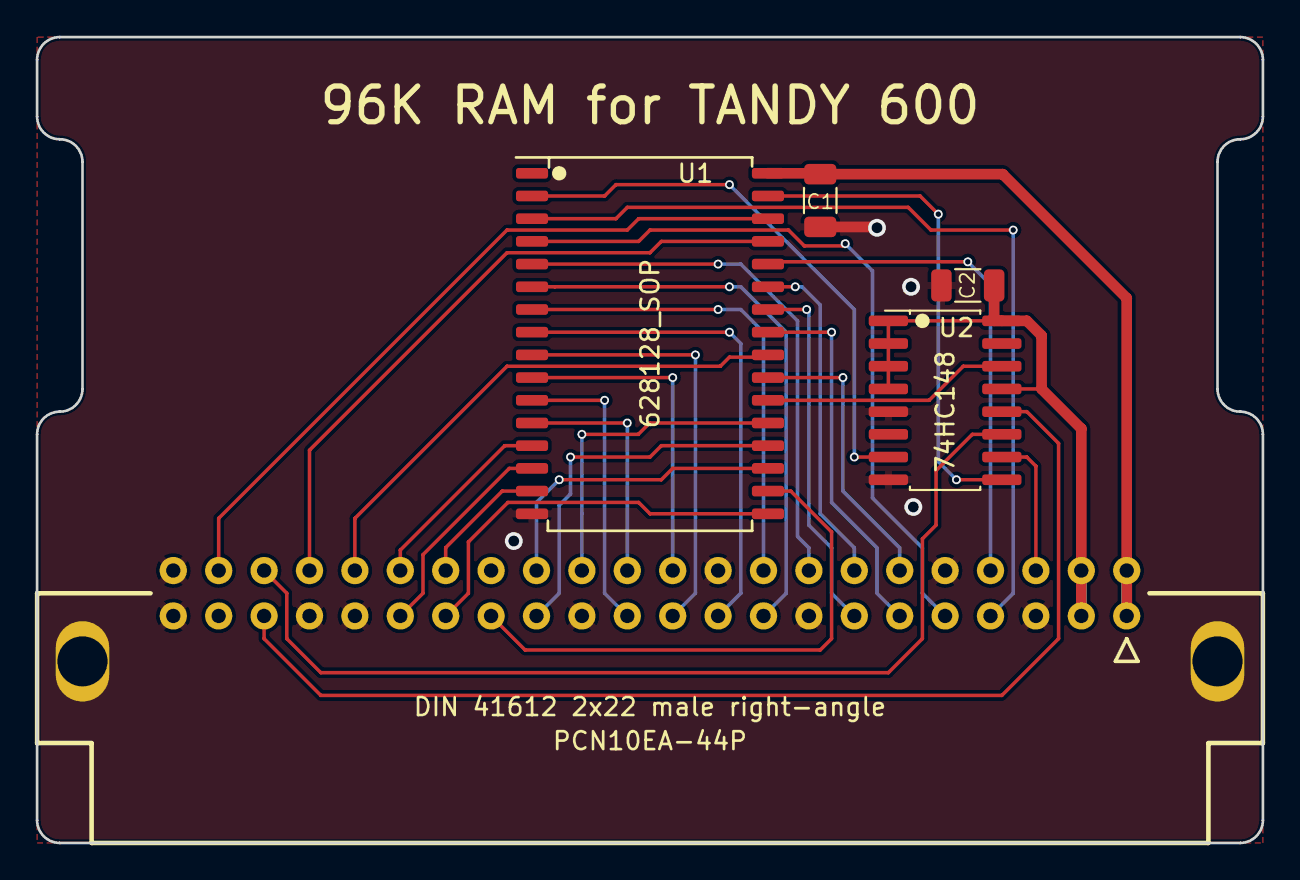
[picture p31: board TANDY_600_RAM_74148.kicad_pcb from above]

Board: 2 copper layers, 68.6 x 45.1 mm, 5 parts (0 on the bottom side), 35 nets.

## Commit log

2021-08-12 JLS-v1.1 original files plus readme & pics
    [Model600Sram.kicad_pcb, Model600Sram.sch]
2021-08-12 re-work into a self-contained project, add 3d models, massage pcb layout
    [Model600Sram.kicad_pcb, Model600Sram.sch, TANDY_600_96K_SRAM.kicad_pcb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]
2021-08-12 remove 74HC08
    [TANDY_600_96K_SRAM.kicad_pcb, TANDY_600_96K_SRAM.sch]
2021-08-12 readme and BOM.csv
    [TANDY_600_RAM.BOM.csv]
2021-08-13 re-order the signal lines so they match from bus to chip
    [TANDY_600_96K_SRAM.kicad_pcb, TANDY_600_96K_SRAM.sch]
2021-09-03 move chip away from edge, add service manual scans
    [TANDY_600_96K_SRAM.kicad_pcb, TANDY_600_96K_SRAM.sch]
2021-09-11 support either SOIC or SOP 74HC148
    [TANDY_600_96K_SRAM.kicad_pcb, TANDY_600_96K_SRAM.sch, TANDY_600_RAM.BOM.csv]
2021-09-28 unscramble cs_a,b,c -> a15,16
    [TANDY_600_96K_SRAM.kicad_pcb, TANDY_600_96K_SRAM.sch]
2021-10-14 More fathomable pinout on the 74148
    [TANDY_600_96K_SRAM.sch]
2022-09-08 kicad 6
    [TANDY_600_96K_SRAM.kicad_pcb, TANDY_600_96K_SRAM.kicad_sch, TANDY_600_96K_SRAM.sch]
2022-09-08 silkscreen, readme, pics
    [TANDY_600_96K_SRAM.kicad_pcb, TANDY_600_96K_SRAM.kicad_sch]
2022-09-16 datasheets, update bom, teardrops on release gerbers
    [TANDY_600_96K_SRAM.kicad_pcb, TANDY_600_96K_SRAM.kicad_sch, TANDY_600_RAM.BOM.csv]
2022-09-16 missing schematic svg
2022-09-18 schematic plot background
2022-09-18 add tiny version
    [TANDY_600_96K_SRAM_tiny.kicad_pcb, TANDY_600_96K_SRAM_tiny.kicad_sch, TANDY_600_RAM_tiny.BOM.csv]
2022-09-19 silkscreen, symbols, footprints touchups
    [TANDY_600_96K_SRAM.kicad_pcb, TANDY_600_96K_SRAM.kicad_sch, TANDY_600_96K_SRAM_tiny.kicad_pcb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]
2022-09-19 re-visible gnd pins on symbols
    [TANDY_600_96K_SRAM.kicad_sch, TANDY_600_96K_SRAM_tiny.kicad_sch]
2022-09-19 add alternative tiny layout, lengthen tsop footprint slightly
    [TANDY_600_96K_SRAM_tiny.kicad_pcb, TANDY_600_96K_SRAM_tiny_alt.kicad_pcb]
2022-09-27 Replace 74148 circuit with 7408 circuit, add THT version, add several variations in ALT dir.
    [TANDY_600_96K_SRAM.kicad_pcb, TANDY_600_96K_SRAM.kicad_sch, TANDY_600_96K_SRAM_tiny.kicad_pcb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]
2022-09-27 tht bom
    [TANDY_600_RAM_THT.BOM.csv]
2022-09-27 tiny bom
    [TANDY_600_RAM_tiny.BOM.csv]
2022-09-29 add DUAL version
    [TANDY_600_RAM_DUAL.kicad_pcb, TANDY_600_RAM_DUAL.kicad_sch]
2022-10-01 wrong sram pinout on dual version
    [TANDY_600_RAM_DUAL.BOM.csv, TANDY_600_RAM_DUAL.kicad_pcb, TANDY_600_RAM_DUAL.kicad_sch]
2022-10-01 tht routing
    [TANDY_600_RAM_THT.kicad_pcb]
2022-10-04 gnd on tiny, new dual sch, bus connector symbol & footprint
    [TANDY_600_RAM.kicad_pcb, TANDY_600_RAM.kicad_sch, TANDY_600_RAM_DUAL.kicad_pcb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]
2022-10-13 pics & updated bom for dual version
    [TANDY_600_RAM_DUAL.BOM.csv]
2022-10-14 main version bom
    [TANDY_600_RAM.BOM.csv]
2022-10-20 add full-size dual
    [TANDY_600_RAM.kicad_pcb, TANDY_600_RAM.kicad_sch, TANDY_600_RAM_DUAL.kicad_pcb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]
2022-10-29 footprints, ground paths
    [TANDY_600_RAM.kicad_pcb, TANDY_600_RAM.kicad_sch, TANDY_600_RAM_DUAL.kicad_pcb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]
2022-10-29 pics & pcb link for THT
2022-10-30 undo accidentally saved filleted tracks on THT
    [TANDY_600_RAM_THT.kicad_pcb]
2022-12-06 dual bom cart link
2022-12-07 bom links text
2022-12-07 readme bom links
2022-12-22 support 256Kx8 chip on dual
    [TANDY_600_RAM_DUAL.kicad_pcb, TANDY_600_RAM_DUAL.kicad_sch, TANDY_600_RAM_DUAL_full.kicad_pcb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]
2022-12-22 tested tiny version, add pcbway link
2023-12-10 dual version add /CE pullup for battery life
    [TANDY_600_RAM.kicad_pcb, TANDY_600_RAM.kicad_sch, TANDY_600_RAM_DUAL.kicad_pcb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]
2023-12-10 dual bom
    [TANDY_600_RAM_DUAL.BOM.csv, TANDY_600_RAM_DUAL_full.BOM.csv]
2024-12-04 footprints on dual
    [TANDY_600_RAM_DUAL.kicad_pcb, TANDY_600_RAM_DUAL.kicad_sch]
2024-12-04 footprints on tiny
    [TANDY_600_RAM_tiny.kicad_pcb, TANDY_600_RAM_tiny.kicad_sch]
2024-12-09 rename 3d dir to 3dshapes to standardize
    [TANDY_600_RAM.kicad_pcb, TANDY_600_RAM.kicad_sch, TANDY_600_RAM_DUAL.kicad_pcb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]
2024-12-20 dual: sch add MPNs & bom, pcb move A14,16,17
    [TANDY_600_RAM_DUAL.bom.csv, TANDY_600_RAM_DUAL.kicad_pcb, TANDY_600_RAM_DUAL.kicad_sch]
2024-12-21 dual: relocate chips for shorter traces & fewer vias, add service manual
    [TANDY_600_RAM_DUAL.kicad_pcb, TANDY_600_RAM_DUAL.kicad_sch]
2024-12-21 dual: sch revision
    [TANDY_600_RAM_DUAL.kicad_sch]
2025-10-29 datasheets OPRM pinout
    [TANDY_600_RAM.kicad_sch, TANDY_600_RAM_DUAL.kicad_pcb, TANDY_600_RAM_DUAL.kicad_sch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]

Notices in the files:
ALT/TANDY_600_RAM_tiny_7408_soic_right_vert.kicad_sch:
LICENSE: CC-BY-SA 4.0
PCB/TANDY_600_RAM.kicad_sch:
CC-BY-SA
